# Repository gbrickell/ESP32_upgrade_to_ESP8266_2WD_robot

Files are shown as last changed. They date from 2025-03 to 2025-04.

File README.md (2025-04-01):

# ESP32 upgrade to the ESP8266 2WD robot

 Plug replaceable upgrade of the ESP8266 2WD robot using an ESP32 and a custom adaptor PCB. By 'plug replaceable' it means that the ESP8266 microcontroller module can be simply removed from the motor controller and replaced by a ESP32 mounted on a custom PCB that acts as an adaptor between the motor controller connectors, that are designed for a ESP8266, and the 38-pin connector of the ESP32 module.

The 3D printed components for the robot are exactly the same as the original ESP8266 project and the designs can be downloaded from [here](https://www.printables.com/model/67808-esp8266-2wd-robot-components). Full details of the upgrade project are documented [here](https://onlinedevices.org.uk/ESP32_upgrade_to_ESP8266_2WD_Robot) and the images below show the overall build in various stages:

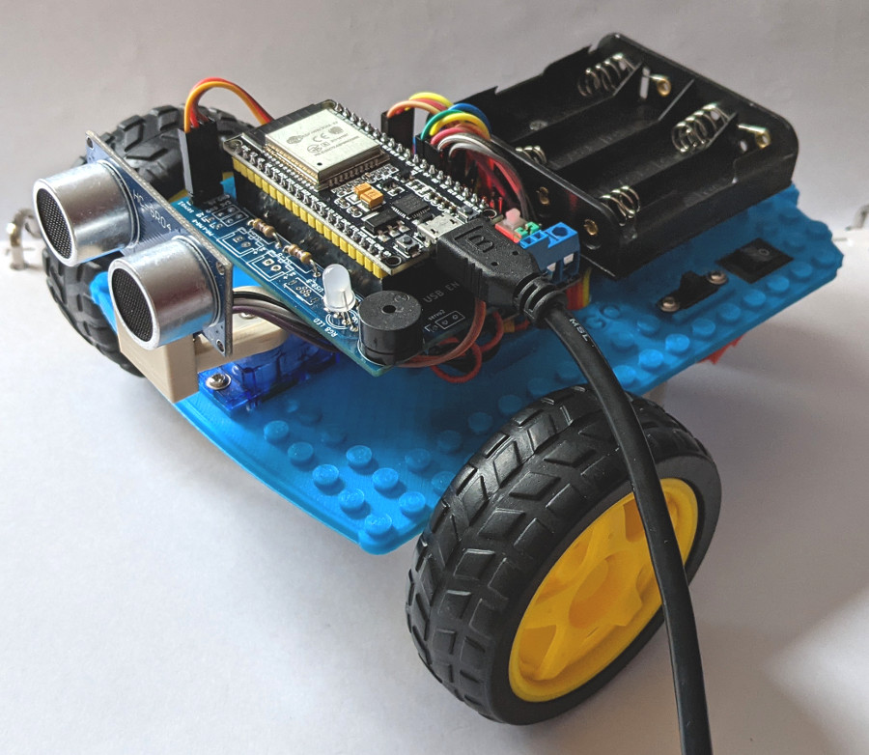
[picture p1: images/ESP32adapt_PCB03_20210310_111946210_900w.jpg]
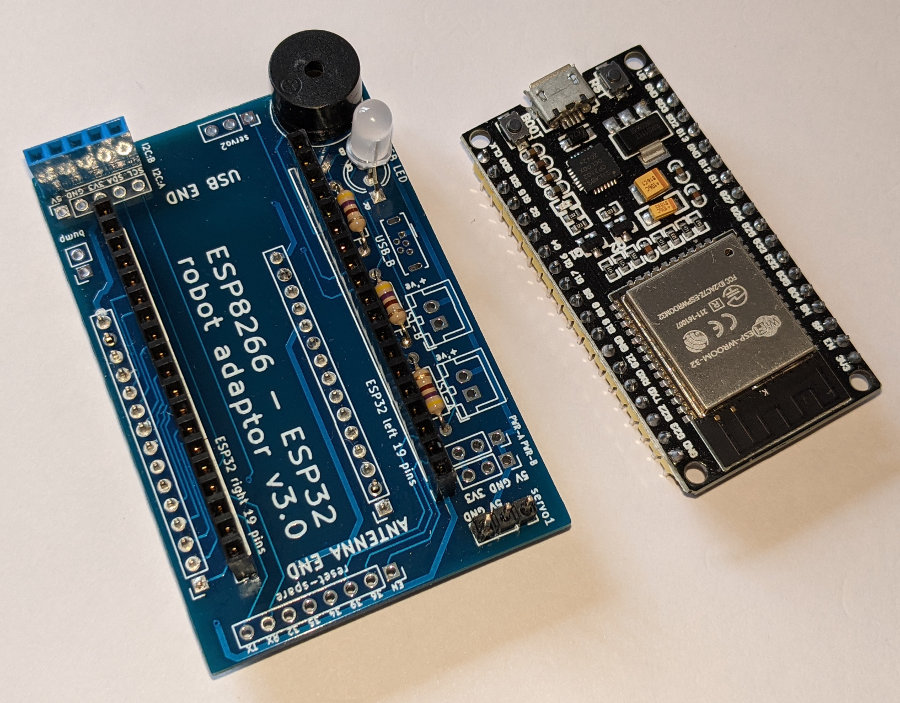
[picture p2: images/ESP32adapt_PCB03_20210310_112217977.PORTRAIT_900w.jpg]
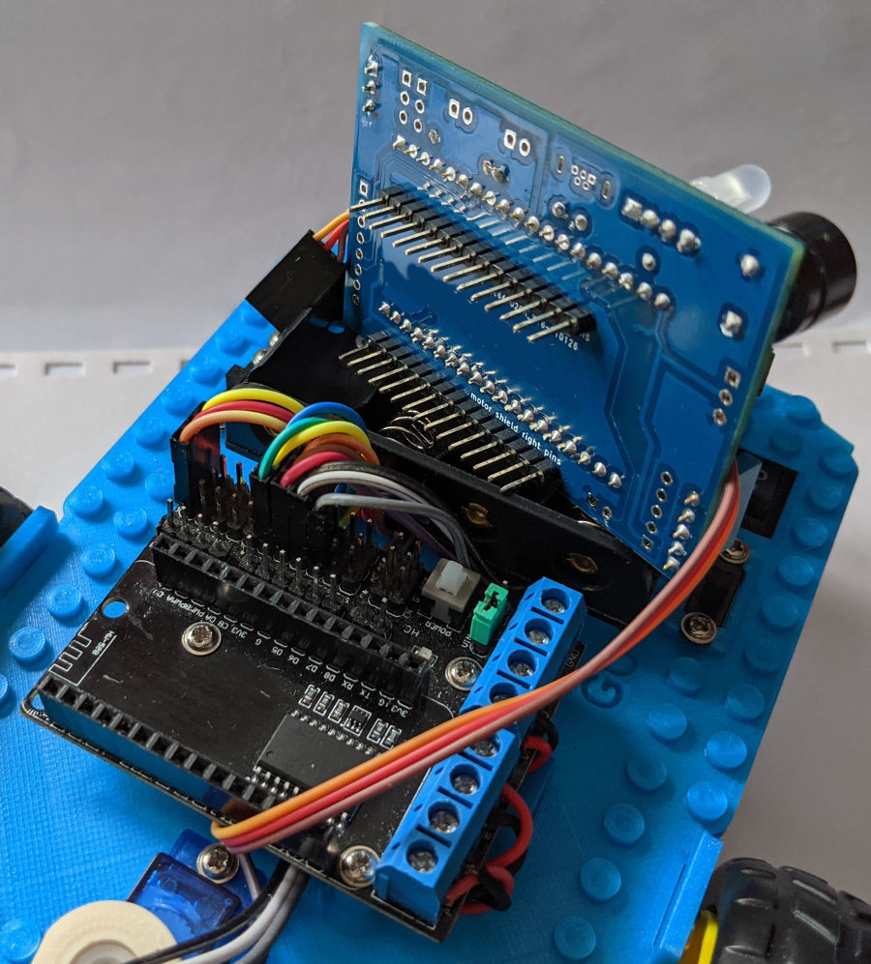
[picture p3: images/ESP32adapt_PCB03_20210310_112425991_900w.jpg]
 &nbsp; &nbsp;   &nbsp; &nbsp; 

Details of the custom PCB are shown in the images below, and the KiCAD design as gerber files can be downloaded from the 'PCB_design_files' folder.

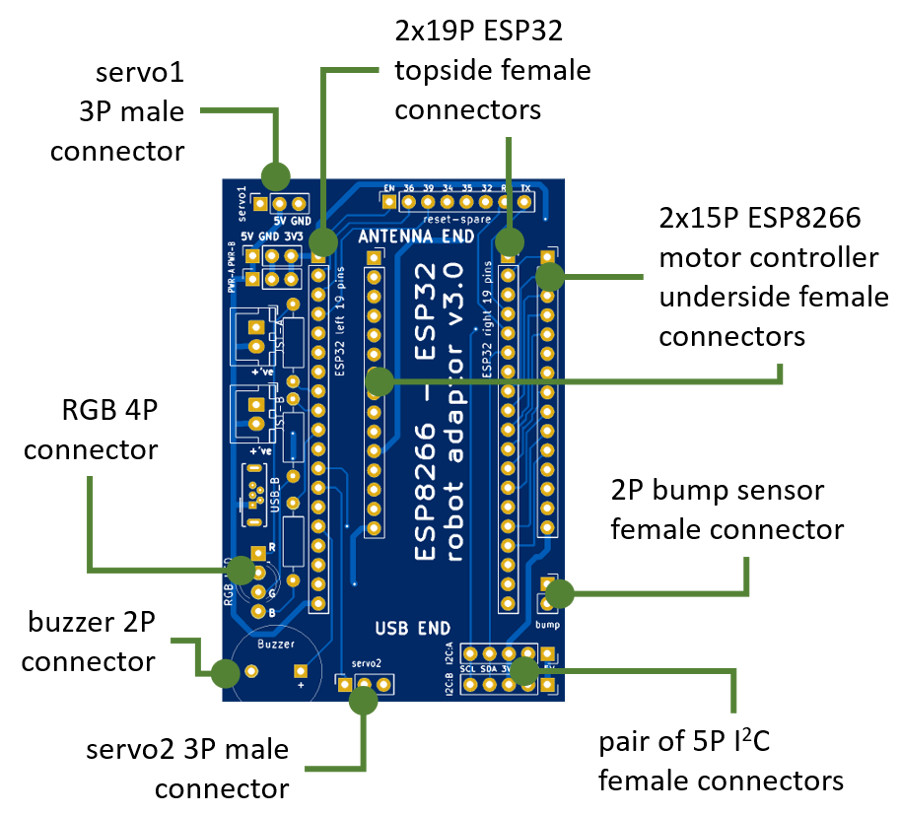
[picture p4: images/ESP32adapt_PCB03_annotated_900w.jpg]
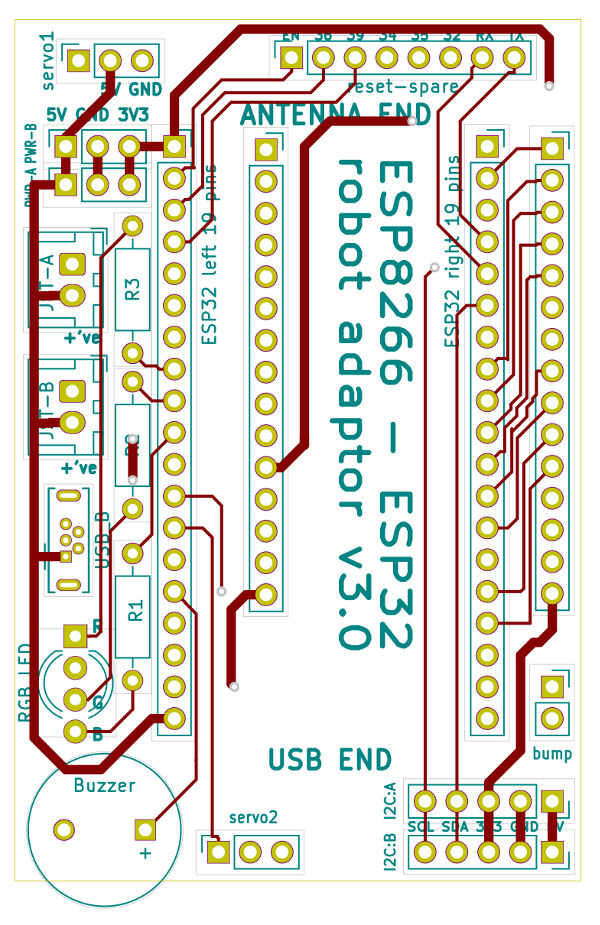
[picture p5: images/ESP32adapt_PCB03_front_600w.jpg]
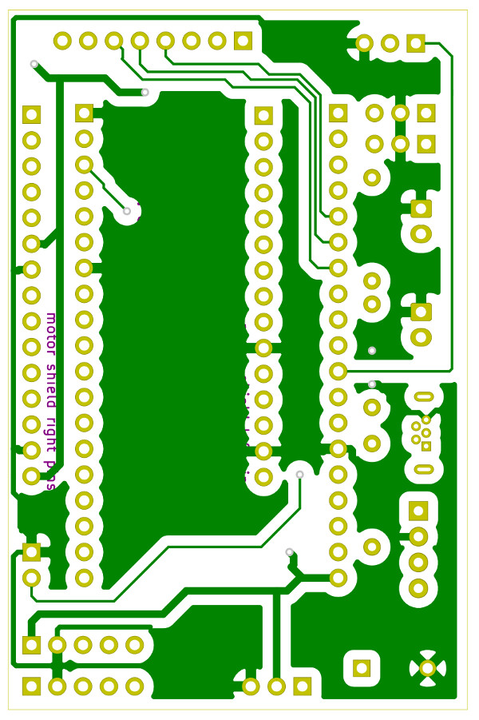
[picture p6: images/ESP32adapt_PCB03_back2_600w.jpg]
 &nbsp; &nbsp;   &nbsp; &nbsp; 

The ESP32 code, downloadable from the 'ESP32_code' folder, was developed on the Arduino IDE and like the original ESP8266 version it uses the 3 slide switches to 'set' a particular operational mode and uses a set of key parameters held in SPIFFS files. These key parameters are all 'set' in the data folder but the folder in the repository is called  'data-public-version', where the details of the optional SSID's and their passwords are just dummy values. These text files therefore need to be updated to the required usage values and the folder renamed as just 'data'.

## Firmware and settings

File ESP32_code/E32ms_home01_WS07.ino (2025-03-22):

// ESP32 update for the NodeMCU8266 with motor shield robot - using the ESP8226 - ESP32 adaptor v3.0
// E32ms_home01_WS05.ino - web server version 04 for the 38 pin ESP32 module connected to the ESP8266 motor shield
//   - builds upon NMms_home01_web_server_20.ino but completely rewritten still using the normal WebServer
//  code developed and compiled using the Arduino IDE v1.8.5
//  ESP32 Dev Module set as the Board in the IDE - using board version 1.0.4
//   even though the board is probably the NodeMCU-32S i.e. 38 pin ESP32
//  Flash Size: 4MB
//  Partition Scheme set to: Default 4MB with spiffs (1.2 MB App / 1.5MB SPIFFS)
// Core Debug Level set to: "Error"
//   lots of other Board settings! but none experimented with

// SPIFF memory initially uploaded using the separate file 'data' upload method

// different versions of this code are used for different robots where the following hard coded parameters are changed:
// - line 61:    String version = "04";
// - line 64:    int IPnum = 10;
// - line 70:    String namehost = "NodeMCU01";
// - line 73:    String softAPref = "home01";

// code uses the slide switch settings to determine what action is taken
// ** opmodes for 3 switches, 1 of which one is the GO/STOP **
// opmode = 4 means AD  softAP web server mode
// opmode = 5 means AC  local WiFi web server mode
// opmode = 6 means BC  autonomous run around mode
// opmode = 8 means BD  demo mode
// opmode = 9 means an undefined operational mode

// both options 4 and 5 use a web server to provide a web interface to control the motors, update files, etc: 
//  now with:
//  - auto stop added to the run-around mode and extensive use of default parameters stored in SPIFFS
//  - demo mode run from a 'action' list file that can be edited from a web page
//  - auto run  and demo run added to web options

#include "WiFi.h"
#include "WebServer.h"
#include <WiFiClient.h>
#include <ESPmDNS.h>         // Include the mDNS library
#include "SPIFFS.h"

#include <StringArray.h>
#include "Arduino.h"
#include "FS.h"
#include "SPIFFS.h"
#include <ESP32Servo.h>  // used for the servo but need to avoid PWM channel conflict
                         //  - so motor PWM channels are set t0 14 & 15

#include "SSD1306Wire.h"        // used for the 128x64 OLED
#include "Open_Sans_Regular_12.h"
#include "Open_Sans_Regular_16.h"
#include "Open_Sans_Regular_18.h"
#include "Open_Sans_Regular_24.h"
#include <LiquidCrystal_I2C.h>  // used for the 16x2 LCD

// -------------------------------------------------------
//  define all the main variables here to make them global
//  some of these variables need ONLY be defined here as 
//  their values are 'read' later from SPIFFS files
// -------------------------------------------------------

// some WiFi variables set here to be global but the WiFi config is done in 
//   the void loop so that it can be either SoftAP or connection to a local WiFi

String version = "05";

// IP addresses for the **soft AP** operation option 4 (AD) switch setting
int IPnum = 10;
IPAddress local_IP(10,0,5,IPnum);     // using a 10.x.x.x IP address space
IPAddress gateway(10,0,5,1);
IPAddress subnet(255,255,255,0);

// hostname as a char variable
const char* namehost = "NodeMCU01";

// softAP device ref
String softAPref = "home01";

WebServer server(80);  //instantiate the web server at port 80 (http port#)

int loopout = 0; // flag for print out at the start of the 'loop' cycle

// buzzer tunes parameters
String notes[110] = {};  // initialise the notes string array
int num_notes;
String str_notes;
String twinkle_melody[42] = {}; // initialise the twinkle_melody string array
String twinkle_tempo[42] = {};  // initialise the twinkle_tempo string array
int num_twinkle = 42;
String adventure_melody[44] = {}; // initialise the adventure_melody string array
String adventure_tempo[44] = {};  // initialise the adventure_tempo string array
int num_adventure = 44;
int buzzpin = 13;    // buzzer GPIO pin

// network credentials to connect to local WiFi networks for the option 5 (AC) switch setting
//  these variables are simply initialised here since it is assumed that all the values have
//  already been 'written' to the appropraite SPIFFS files or will be populated via the web 
//  interface using the softAP option
// N.B. variables are all strings BUT thse need to be converted to a char for use with the WiFi
String ssid_selected ="";
int NSSIDs = 5;   // number of local WiFi credentials that can be set up: the first one found is used
String ssid1 = " ";
String ssid2 = " ";
String ssid3 = " ";
String ssid4 = " ";
String ssid5 = " ";
String password1 = " ";
String password2 = " ";
String password3 = " ";
String password4 = " ";
String password5 = " ";

// demo action variables: option 8 - slide switch BD, runs these actions on a continuous basis when in GO mode
int num_demo = 40;              // maximum number of demo actions allowed
String demo_controls[40] ={};   // pairs of strings in an array that define the demo actions
String demo_actions[9] ={};     // array of all the potential demo action command strings

// variable to indicate whether either of the two WiFi options have been set up
// this is needed since the setup is different per switch option, so the set up
//   must be done within the "void loop()" and reset if the switch settings change
const char* WiFiup = "no";

String page_content = "";   // initialised global variable for web page content
String web_server = "off";  // 'off' just means the robot is in logical STOP mode so a limited web page is shown

String server_started = "no";  // logic flag so the server is not started until a WiFi connection has been set up

// ************************************************
// define all the motor operation variables
//  again just initialised here as the values are
//  assumed to be 'read' from SPIFFS files
// ************************************************
int turntime = 1200;     // time in ms to do a 90-deg turn (read later from SPIFFS)
int spintime = 1200;     // time in ms to do a 90-deg spin (read later from SPIFFS)
int turnspeed = 90;      // turning speed as a % (read later from SPIFFS)
int spinspeed = 90;      // spinning speed as a % (read later from SPIFFS)

// power adjustment for left/right motors (read later from SPIFFS) i.e.
// set motorL to <1 if turning to the right or 
//     motorR to <1 if turning to the left
float motorL = 1.0;   
float motorR = 1.0;

int r_speed = 90;         // default speed % as an integer value  0-100%

// ** motor drive **
// pins used when the ESP32 + adaptor are inserted into the motor shield
// pin 19 -  motor A: HIGH for 100% forward or PWM duty cycle 0-255 for PWM%
// pin 18 -  motor B: HIGH for 100% forward or PWM duty cycle 0-255 for PWM%
// pin 5  -  motor A direction: LOW = FWD - HIGH = BACK
// pin 17 -  motor B direction: LOW = FWD - HIGH = BACK

int PWMpinA = 19;
int PWMpinB = 18;
int dirpinA = 5;
int dirpinB = 17;

// motor A wired as the left motor when facing forwards
// motor B wired as the right motor when facing forwards

// ***************************************************************************
// set the PWM parameters for use with the LED PWM function which is used
// for motorcontrol - ledc must be used as analogWrite is not on the ESP32
// 16 channels can be used and resolution=8 gives PWM range 0-255 i.e. 2**8-1
//  - but need to avoid channels 0 & 1 to avoid servo conflict
// ***************************************************************************
const int freq = 300;
const int pwmChannelA = 14;  // using a channel at the end of the allowed number
const int pwmChannelB = 15;  //  which seems to avoid a conflict with the servo function
const int resolution = 8;
int dutyCycle = 0;
int dutythreshold = 110;   // minimum duty cycle needed to turn the motors @10%

// ***************************************************************
// set the robot state variable used in the HTML page generation
//  for various logic checks e.g.  to colour the buttons
// 0 means: robot STOP
// 1 means: robot FORWARDS
// 2 means: robot BACKWARDS
// 3 means: robot EMERGENCY STOP
// ***************************************************************
int robot_state = 0;

// ***************************************************************
// set the web state variable used in various places
//  for various logic checks e.g.  in bump detection logic
// 0 means: undefined stste
// 1 means: 'run about' selected
// 2 means: 'auto run' selected
// 3 means: 'demo' selected
// 4 means: 'component testing' selected
// 5 means: 'update parameters' selected
// 6 means: 'system info' selected
// 7 means: '??' selected
// ***************************************************************
int web_state = 0;

// *************************************
// set all the slide switch variables
// *************************************
int s_debug = 1;       // 1 = debug on  0 = debug off
int num_switches = 3;  // this variable is hard-coded as either 3 or 4 so that the same 
                       //  logic/function can be used with different numbers of switches
                       //  the current ESP32 robot build only uses 3 switches 
int opmode = 0;        // set to an initial IDLE state
int opmode_last = 10;  // set to an initial impossible value
int swmode = 0;        // set to an initial OFF state
int swmode_last = 10;  // set to an initial impossible value

// set ESP32 slide switch pin variables
//  these are fully set initially here otherwise nothing can be operated!!
//   even though all the GPIO pins can (exceptionally!) be updated
//   via the web interface if for some reason the robot is rewired
int s_AB  = 16;
int s_CD  = 4;
int s_EF  = 99;  // not used in early NodeMCU builds so num_switches above should be set to 3
int onoff = 23;

// set initial switch states to something undefined so that the program checks can run from the start
int state_onoff = 2;
int state_AB = 2;
int state_CD = 2;
int state_EF = 2;

// set which switch setting modes are active, i.e. programmed (1) or inactive (0)
//  will need to updated in the code if more switch setting options are coded
int mode_1 = 0;
int mode_2 = 0;
int mode_3 = 0;
int mode_4 = 1;  // softAP web interface
int mode_5 = 1;  // local WiFi web interface
int mode_6 = 1;  // autonomous run around
int mode_7 = 0; 
int mode_8 = 1;  // demo mode

// ***************************
// ultrasonic sensor variables
// ***************************
// uses an HC-SR04P (3V3 version) Ultrasonic Sensor connected to the #2 (trig) and #15 (echo) pins
int trigPin = 2;    // pin #2 used for the sensor Ping Pin (Trig)
int echoPin = 15;   // pin #15 used for the sensor Echo Pin (Echo)
unsigned long duration, inches;
int indec, cmdec;  // not needed??
int inchconv = 147; // ratio between pulse width and inches
int cmconv = 59;    // ratio between pulse width and cm
int avoid_distance = 20;   // set a defined distance to take avoidance action
int avoid_limit = 2;       // number of times distance limit is reached before action taken - avoids spurious readings
int avoid_count = 0;       // number of times that distance limit is reached
int cm, lcm, rcm;          // calculated U/S distance variables for static or servo mount options

const char* leftright = "right";
int avoidspintime = 600;   // time in ms to spin in the avoidance routine
int ReverseTime = 350;     // time in ms to reverse in the avoidance routine
String stopauto = "yes";   // set whether autostop should be used
String cm_str = "";

// *******************************************
// set the various servo variables
// *******************************************
// uses a SG90 servo connected to the #27 pin via the servo1 pins on the the adaptor PCB
//  recommended PWM GPIO pins on the ESP32 include 2,4,12-19,21-23,25-27,32-33
int swivelPin = 27;     // this is servo1 on the adaptor PCB
int swivelCentre = 100; // set this 'offset' to be dead ahead setting (or adjust servo horn mounting)
                        // for servo installed with wires exiting from the front: -'ve = right & +'ve = left
Servo swivelServo;      // N.B. this seems to always take channels 0 & 1 so need to use others for motor PWM

// *******************************************
// set the various RGB LED variables
// *******************************************
const int redPin = 33;
const int greenPin = 25;
const int bluePin = 26;

// ******************************
// set the bump switch variables
// ******************************
int bumpPin = 14;
bool bumpsensed = false;

// ********************************************************
// String versions of the various integer variables
// - easier to deal with in SPIFFS and web pages! even 
//   though this creates overhead with various conversions
// ********************************************************
String str_NSSIDs = String(NSSIDs);
String str_mode_1 = String(mode_1);
String str_mode_2 = String(mode_2);
String str_mode_3 = String(mode_3);
String str_mode_4 = String(mode_4);
String str_mode_5 = String(mode_5);
String str_mode_6 = String(mode_6);
String str_mode_7 = String(mode_7);
String str_mode_8 = String(mode_8);

String str_num_switches = "3";
String str_s_AB ="16";
String str_s_CD = "4";
String str_s_EF = "99";
String str_onoff = "23";

String str_trigPin = "2";
String str_echoPin = "15";
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
void loop() {
    // the code here runs repeatedly in a loop

    if (loopout == 0) {
        Serial.print("loop() running on core ");
        Serial.println(xPortGetCoreID());
        loopout = 1;  // set the loopout parameter so that the loop is only executed once
    }
    
    // get the latest swmode and opmodes from the switch settings
    swmode = check_onoff(swmode_last, s_debug, onoff);
    opmode = check_slideswitch(num_switches, opmode_last, s_debug, s_AB, s_CD, s_EF);
    if (opmode != opmode_last) {  // print out the opmode if it has changed but don't reset so it can be done later
        Serial.print (" new switch settings and therefore new opmode: ");
        Serial.println(opmode);
        // but change WiFi status since this may have to be reset
        WiFiup = "no";
    }

    // ** only opmodes 4, 5, 6 & 8 are possible with 3 switches so only these are currently checked in this code **

    // ##############################################################
    // ## opmode 4 inactive: run web server with the softAP option ##
    // ##############################################################
    if (opmode == 4 and swmode == 0) {
        stop();     // stop the motors just in case something has been left running
        swivel(0);  // ... and centre the servo
        if (mode_4 == 0) {
            if (opmode_last != 4 or swmode_last !=0) {
                Serial.println ("opmode 4 - (AD) not set up yet - CODE INACTIVE ");
                opmode_last = 4;
                swmode_last = 0;
                RGB_color("red");  // set to red to signify an unallowed operation
                if (str_OLED64x128 == "yes") {oledtext(3, 0, 0, 0, 0, 16, "softAP mode", "code not", "set up", "");}
                if (str_LCD16x2 == "yes") {lcdtext(0, 0, "softAP mode", "code not set up");}
            }
        } else {           
            if  (opmode_last != 4 or swmode_last !=0 ) {           
                Serial.println ("opmode 4 - 3 switches: (AD) web server operation - in logical STOP mode");
                opmode_last = 4;
                swmode_last = 0;
                web_server = "off";  // set flag to show minimal web content
                RGB_color("blue");  // set to blue to signify an allowed operation but in STOP mode
                if (str_OLED64x128 == "yes") {oledtext(3, 0, 0, 0, 0, 16, "softAP mode", "STOP set", "", "");}
                if (str_LCD16x2 == "yes") {lcdtext(0, 0, "softAP mode", "STOP set");}
            }
            // run limited opmode4 actions for STOP condition

            if (WiFiup == "no") {
                setupSoftAP();
            }

            server.handleClient();  // look for an HTTP request from a browser
        }

    }

    // ##############################################################
    // ##  opmode 4 active: run web server with the softAP option  ##
    // ##############################################################
    else if (opmode == 4 and swmode == 1) {
        if (mode_4 == 0) {
            stop();     // stop the motors just in case something has been left running
            swivel(0);  // ... and centre the servo
            if (opmode_last != 4 or swmode_last !=1) {
                Serial.println ("opmode 4 - (AD) not set up yet - CODE INACTIVE ");
                opmode_last = 4;
                swmode_last = 1;
                RGB_color("red");  // set to red to signify an unallowed operation
                if (str_OLED64x128 == "yes") {oledtext(3, 0, 0, 0, 0, 16, "softAP mode", "code not", "set up", "");}
                if (str_LCD16x2 == "yes") {lcdtext(0, 0, "softAP mode", "code not set up");}
            }
        } else {           
            if  (opmode_last != 4 or swmode_last !=1 ) {           
                Serial.println ("opmode 4 - 3 switches: (AD) web server operation - in logical GO mode");
                stop();             // stop the motors just as a start condition
                web_server = "on";  // set flag to show full web content
                opmode_last = 4;
                swmode_last = 1;
                RGB_color("green");  // set to green to signify an allowed operation in GO mode
                if (str_OLED64x128 == "yes") {oledtext(3, 0, 0, 0, 0, 16, "softAP mode", "GO set", "", "");}
                if (str_LCD16x2 == "yes") {lcdtext(0, 0, "softAP mode", "GO set");}
            }

            // run opmode4 actions for GO condition
            if (WiFiup == "no") {
                setupSoftAP();
            }

            int obdist = getDistance();     // check distance for potential need for an autostop
            // keep checking the distance from the ultrasonic sensor but only when going forward
            if (robot_state == 1 and obdist < stop_distance and stopauto == "yes") 
            {
               handle_diststop();      // stops robot 'outside' of the web interface
               Serial.print ("emergency stop distance: ");
               Serial.println (obdist);
            }

            server.handleClient();  // look for an HTTP request from a browser
        }

    }

    // #########################################################################
    // ## opmode 5 inactive: run web server with local WiFi connection option ##
    // #########################################################################
    else if (opmode == 5 and swmode == 0) {
        stop();     // stop the motors just in case something has been left running
        swivel(0);  // ... and centre the servo
        if (mode_5 == 0) {
            if (opmode_last != 5 or swmode_last !=0) {
                Serial.println ("opmode 5 - (AD) not set up yet - CODE INACTIVE ");
                opmode_last = 5;
                swmode_last = 0;
                RGB_color("red");  // set to red to signify an unallowed operation
                if (str_OLED64x128 == "yes") {oledtext(3, 0, 0, 0, 0, 16, "local WiFi mode", "code not", "set up", "");}
                if (str_LCD16x2 == "yes") {lcdtext(0, 0, "local WiFi mode", "code not set up");}
            }
        } else {           
            if  (opmode_last != 5 or swmode_last !=0 ) {           
                Serial.println ("opmode 4 - 3 switches: (AD) web server operation - in logical STOP mode");
                opmode_last = 5;
                swmode_last = 0;
                web_server = "off";  // set flag to show minimal web content
                RGB_color("blue");  // set to blue to signify an allowed operation but in STOP mode
                if (str_OLED64x128 == "yes") {oledtext(3, 0, 0, 0, 0, 16, "local WiFi mode", "STOP set", "", "");}
                if (str_LCD16x2 == "yes") {lcdtext(0, 0, "local WiFi mode", "STOP set");}
            }
            // run limited opmode5 actions for STOP condition

            if (WiFiup == "no") {
                setuplocalWiFi();
            }

        }
    }

    // ########################################################################
    // ##  opmode 5 active: run web server with local WiFi connection option ##
    // ########################################################################
    else if (opmode == 5 and swmode == 1) {
        if (mode_5 == 0) {
            if (opmode_last != 5 or swmode_last !=1) {
                Serial.println ("opmode 5 - 3 switches: (AC) not set up yet - CODE INACTIVE ");
                opmode_last = 5;
                swmode_last = 1;
                RGB_color("red");  // set to red to signify an unallowed operation
                if (str_OLED64x128 == "yes") {oledtext(3, 0, 0, 0, 0, 16, "local WiFi mode", "code not", "set up", "");}
                if (str_LCD16x2 == "yes") {lcdtext(0, 0, "local WiFi mode", "code not set up");}
            }
        } else {           
            if  (opmode_last != 5 or swmode_last !=1 ) {           
                Serial.println ("opmode 5 - 3 switches: (AC) in logical GO mode");
                opmode_last = 5;
                swmode_last = 1;
                web_server = "on";  // set flag to show full web content
                RGB_color("green");  // set to green to signify an allowed operation in GO mode
                if (str_OLED64x128 == "yes") {oledtext(3, 0, 0, 0, 0, 16, "local WiFi mode", "GO set", "", "");}
                if (str_LCD16x2 == "yes") {lcdtext(0, 0, "local WiFi mode", "GO set");
            }
            // run opmode5 actions for GO condition

            if (WiFiup == "no") {
                setuplocalWiFi();
            }
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
